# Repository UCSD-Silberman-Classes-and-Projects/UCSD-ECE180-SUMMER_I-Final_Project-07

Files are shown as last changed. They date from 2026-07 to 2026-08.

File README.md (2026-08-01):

# UCSD-ECE180-SUMMER_I-Final_Project-07

<div align="center">

</div>
  
</body>

<h1 align="center">Anti-Shrapnel Roomba</h1>
<h4 align="center"></h4>
<!-- PROJECT LOGO -->
<div align="center">

<h3>ECE 180 Final Project</h3>
<p>
Team 7 Summer I 26'
</p>

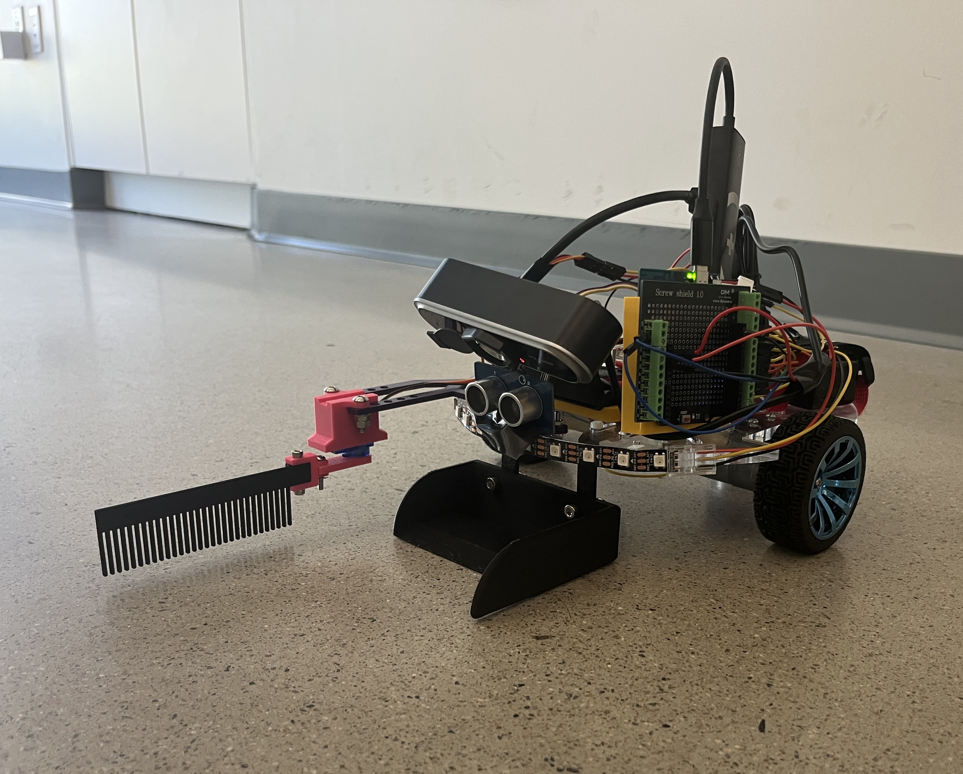
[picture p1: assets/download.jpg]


</div>

<!-- TABLE OF CONTENTS -->
<details>
  <summary>Table of Contents</summary>
  <ol>
    <li><a href="#team-members">Team Members</a></li>
    <li><a href="#final-project">Final Project</a></li>
      <ul>
        <li><a href="#original-goals">Original Goals</a></li>
          <ul>
            <li><a href="#goals-we-met">Goals We Met</a></li>
            <li><a href="#our-hopes-and-dreams">If We Have Another Week...</a></li>
         </ul>
       </ul>
    <li><a href="#final-project-documentation">Final Project Documentation</a></li>
    <ul>
      <li><a href="#CAD-Design">CAD Design </a></li>
      <ul>
            <li><a href="#modeled-ourselves">Modeled Ourselves</a></li>
            <li><a href="#open-source-parts">Open Source Parts</a></li>
          </ul>
        <li><a href="#Software">Software</a></li>
          <ul>
            <li><a href="#how-to-run">How to Run</a></li>
          </ul>
      </ul>
    <li><a href="#authors">Authors</a></li>
    <li><a href="#acknowledgments">Acknowledgments</a></li>
    <li><a href="#contact">Contact</a></li>
  </ol>
</details>

<!-- TEAM MEMBERS -->
## Team Members

<ul>
  <li>Raul -  Electrical Engineering - '27</li>
  <li>Tristan -  Electrical Engineering - '28</li>
  <li>AnMei - Computer Engineering - '27</li>
</ul>

<!-- Final Project -->
## Final Project
<!-- put stuff here -->

<!-- Original Goals -->
### Original Goals
Our initial goal was to build a Roomba-style robot that collects small hazardous objects (like sharp objects) from a workshop or playroom. Using an Arduino Uno Q with a webcam, the robot would identify sharp objects in its path. Must-have functionality included identifying sharp objects, collecting the identified objects, tracking how many objects were collected so as not to surpass the sweeper's hardcoded limit of 1, and navigating the space independently. Nice-to-have stretch functionality included ringing an alarm once the sweeper was full, having a child/baby mode (e.g. picking up Legos), and displaying the object count.
<!--example non visible text here -->
   
<!-- End Results -->
### Goals We Met
We successfully built a robot that identifies sharp objects, collects the identified objects, and tracks how many objects are collected so as not to surpass the sweeper's limit, all while navigating spaces independently although it still has bugs and inconsistencies. This can be seen in the demo below. We also succeeded in displaying the object count, going beyond our must-haves and hitting one of our nice-to-haves. For object detection, we initially planned to use a YOLO pro nano model but found it too laggy, so we used a FOMO model instead which made slightly quicker inferences.

### If We Have Another Week...
If we had one more week, we would implement a gyro (IMU) to improve direction in robot navigation as the current build using encoders and PID is effective but not perfect. We would also add a user interface to to allow users to give a rough estimate of the play area or area to be covered by the robot as it is currently hardcoded. Additionally, we would also try to improve the accuracy of our computer vision model as only two of several trained objects were picked up with one of them being inconsistent. We would also move the current location of the ultrasonic sensor and make another mount for the ultrasonic sensor as it's currently location underneath the camera would sometimes be set off at random times. This would happen rarely but is still an issue needing to be addressed. We would also improve the design of the current brush and dustbin as the current build would sometimes cause bigger objects to not be caught. The brush needs improved griping capabilities and the dustbin just needs to be made wider.

## Final Project Documentation

<!-- Early Quarter -->
### CAD Design
<!--<img src="/media/full%20car%20cad.png" width="400" height="300" />-->

#### Modeled Ourselves
| Part | CAD Model |
|---|---|
| Uno Q | <a href="assets/U Mount.stl"> Case Mount|
| Dustbin | <a href="assets/Dustbin.stl"> Extended Dustbin|
| Brush | <a href="assets/Comb.stl"> Brush|
| Servo | <a href="assets/Arm.stl"> Servo Arm Connector|
| Servo | <a href="assets/Hinges.stl"> Hinge to connect Comb and Servo|
| Ultrasonic Sensor | <a href="assets/Sensor Mount.stl"> Sensor Mount|

#### Open Source Parts
| Part | CAD Model |
|---|---|
| Uno Q Case | <a href="assets/arduino-uno-q-case.3mf"> Case|
| Servo | <a href="assets/SG90%20Servo%20Mount.stl"> Mount|

### Software / App Lab setup
- Arduino App Lab, with this project's Bricks added (via App Lab's Brick UI,
  not just imported in code):
  - **Video Object Detection** -- with your trained AI model selected under
    its "AI models" tab
  - **Web UI** -- serves the camera viewer / item counter page in the browser
- `sketch/sketch.ino` requires the **Servo** library (installed automatically
  by App Lab from the sketch's library list)
- `python/main.py` requires `pygame` (for the joystick placeholder --
  currently unused by autonomous mode itself, but imported)

#### Component List
| Component | Purpose|
|---|---|
| Arduino Uno Q | On board compute |
| SG 90 Micro Servo | To make brush do sweeping motion |
| Ultrasonic Ranger Sensor | To prevent bot from crashing into walls or furniture|
| PDB-XPW | Provide/distribute power from 3 Cell 12 V Lipo Battery to robot |
| L298N Motor Driver | Controls speed, direction, power of 2 DC motors |
| 2 JGA25-370 6V DC Motors with Encoders | Allows the robot to navigate with more precision with encoders |
| Generic 1080P 5V Webcam | Allow AI model to determine identity of objects |
| USB C Hub | Connects Arduino and Webcam to one another while also providing power from PDB |
| 3 Cell 12 V Lipo Battery | Provides power to entire robot |

### Wiring
| Component | Pin |
|---|---|
| Left motor ENA / IN1 / IN2 | D9 / D4 / D5 |
| Right motor ENB / IN3 / IN4 | D3 / D6 / D7 |
| Left encoder (Yellow) | D8 |
| Right encoder (Yellow) | D2 |
| Ultrasonic SIG | D10 |
| Sweeper servo | D11 |

## How to run

1. Using Encoder Calibration files, run the app to calibrate encoders for first time use. Can skip if already set.
2. Using Ultrasonic Sensor Testing files, run a few sets measurements of sensor are accurate as this can throw off limits set for wall or furniture detection. Can skip if already checked.
3. Open Autonomous Movement with Cam project in App Lab and hit **Run**.
4. The app waits `STARTUP_DELAY_SECONDS` (currently 5s) before any movement
   starts, giving the camera stream time to come up. Use this window to open
   the WebUI in your browser (it doesn't always auto-pop-up -- see
   Troubleshooting below).
5. Movement mode is controlled by `TEST_MODE` near the top of `main.py`:

| `TEST_MODE` | What it does |
|---|---|
| `"drive"` | Drives forward `TEST_DRIVE_DISTANCE_CM` once, no camera checks |
| `"turn"` | Turns `TEST_TURN_DEGREES` in place, no camera checks |
| `"creep"` | One row, in small increments, pausing for the camera between each -- pickup/avoid/obstacle all active, with camera checks |
| `"creep2"` | Two rows (creep mode) with a turn in between, with camera checks |
| `"sweep2"` | Two rows, full continuous speed, **no** camera checks (movement/turn-geometry test only) |
| `"sweep"` | Full lawnmower coverage of the whole play area, no camera checks |

Set the mode, save, and hit Run again.

## Troubleshooting

- **WebUI doesn't auto-pop-up**: check App Lab's own preview/open link, or
  navigate to `http://localhost:7000` (or the board's network IP) manually.
  This has been unreliable but is cosmetic -- the app works fine either way.
- **Behavior doesn't match your latest code change**: do a clean rebuild
  before assuming the code is wrong:
  ```
  cd ~/ArduinoApps/autonomous-movement-with-cam
  docker compose -f .cache/app-compose.yaml down
  rm -rf .cache
  ```
  Then hit Run again in App Lab. Worth doing anytime you change Bricks,
  `app.yaml`, or the WebUI's static files (`index.html`/`app.js`).
- **Sketch fails to compile with "redefinition of ..." errors**: the file
  wasn't fully replaced when pasted -- clear `sketch/sketch.ino` completely
  before pasting in a new version, don't paste on top of existing content.
- ** Ultrasonic Testing files included if issues come up with sensor.

## Final Project Presentation Slides
<a href= "https://docs.google.com/presentation/d/1Zw6ZW6a8-33r7sMMGZXmiMXOQ0kt0MH9-cVSyJLGKLM/edit?usp=sharing">Final Project Demonstration Slides

## Video Demos
<a href= "https://youtube.com/shorts/Sm3MTq7GF2I?feature=share">Robot Navigating Demo

<a href= "https://youtube.com/shorts/Sm3MTq7GF2I?feature=share">Robot Avoiding Non-sharp Object Demo

<a href= "https://youtube.com/shorts/Sm3MTq7GF2I?feature=share">Robot Sweeps Sharp Object Demo

<a href= "https://youtube.com/shorts/Sm3MTq7GF2I?feature=share">Robot Fails to Sweep Sharp Object Demo

## FOMO Model
<a href= "https://studio.edgeimpulse.com/public/1059185/latest">Here 

<!-- Authors -->
## Authors

Raul, Tristan, and AnMei

<!-- ACKNOWLEDGMENTS -->
## Acknowledgments
Much appreciation to Professor Silberman, TA Jose, and classmates.

<!-- CONTACT -->
## Contact

* Raul | rbmagana@ucsd.edu
* Tristan | ttjussardi@ucsd.edu
* AnMei | adasbachprisk@ucsd.edu

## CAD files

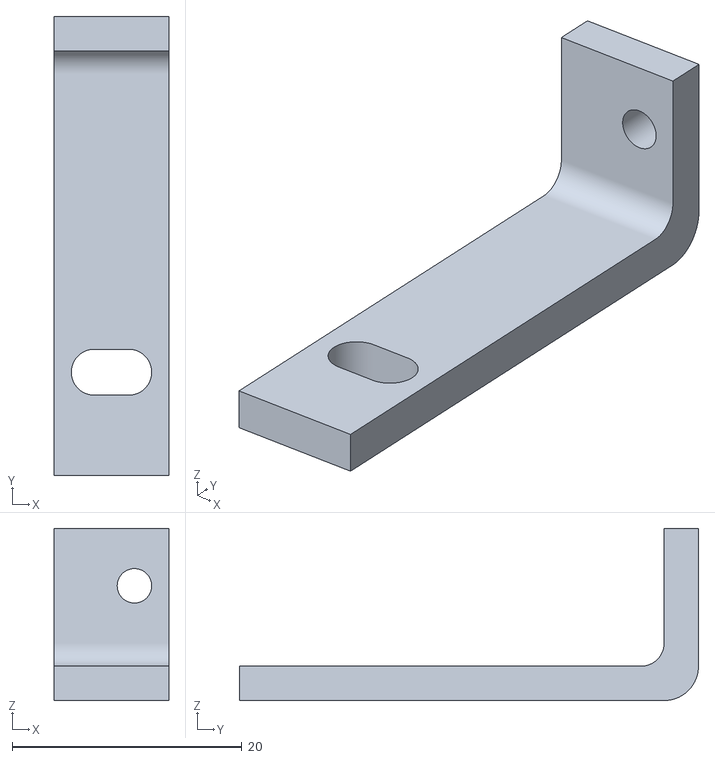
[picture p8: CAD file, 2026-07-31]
assets/Hinges.stl
10.0 x 40.0 x 15.0

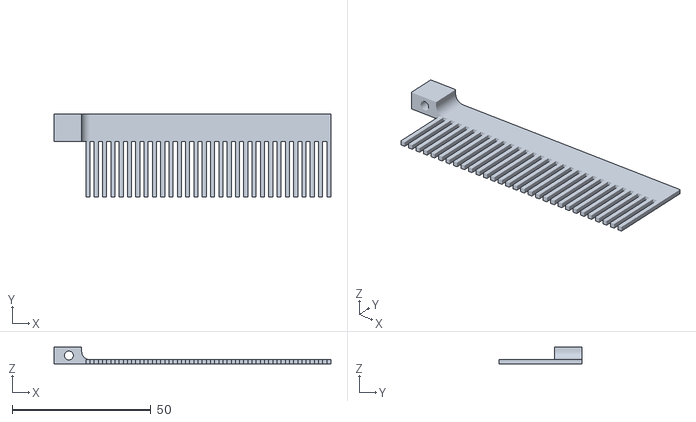
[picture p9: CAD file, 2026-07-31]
assets/Comb.stl
100.0 x 30.0 x 6.00

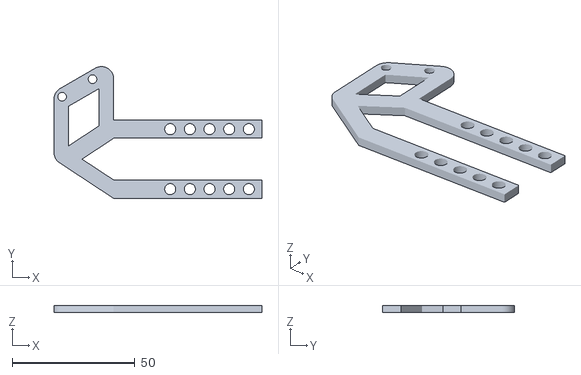
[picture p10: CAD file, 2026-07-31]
assets/Servo Mount.stl
84.6 x 53.7 x 3.00

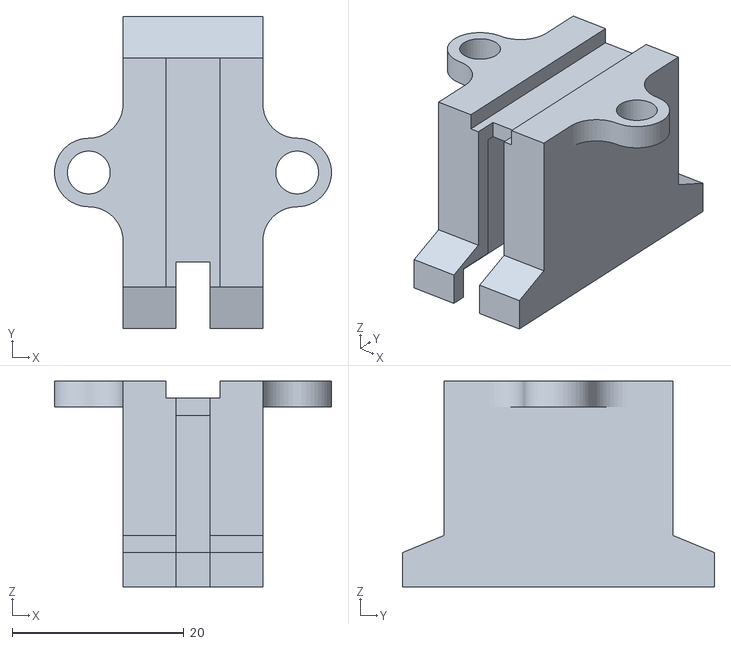
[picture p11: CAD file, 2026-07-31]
assets/SG90%20Servo%20Mount.stl
32.3 x 36.4 x 24.0

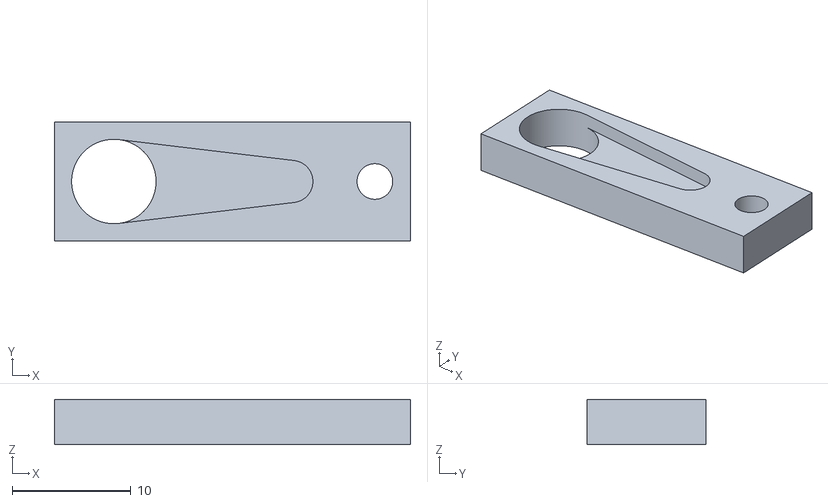
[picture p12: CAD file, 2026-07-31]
assets/Arm.stl
30.0 x 10.0 x 3.80

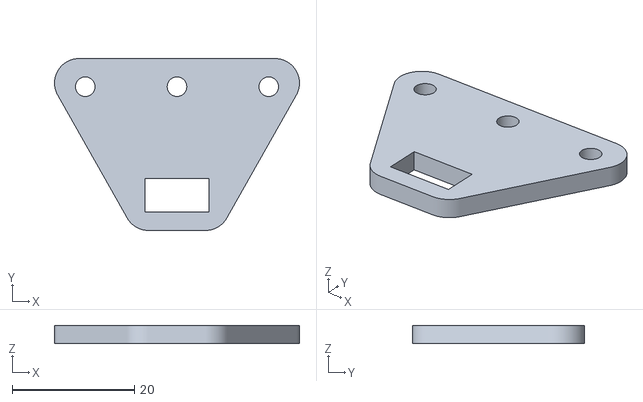
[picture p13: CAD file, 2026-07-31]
assets/Sensor Mount.stl
40.1 x 28.1 x 3.00

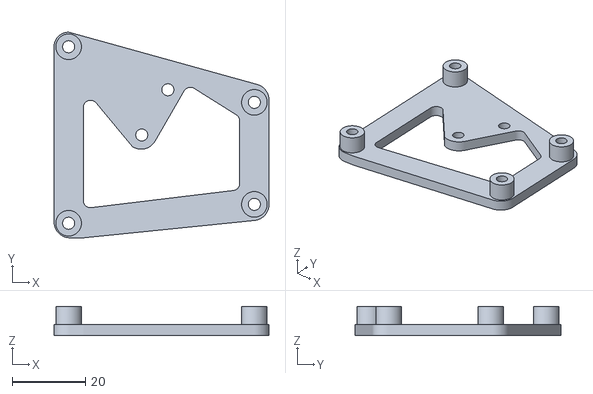
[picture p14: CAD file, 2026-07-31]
assets/Arduino Mount.stl
58.8 x 56.3 x 8.00

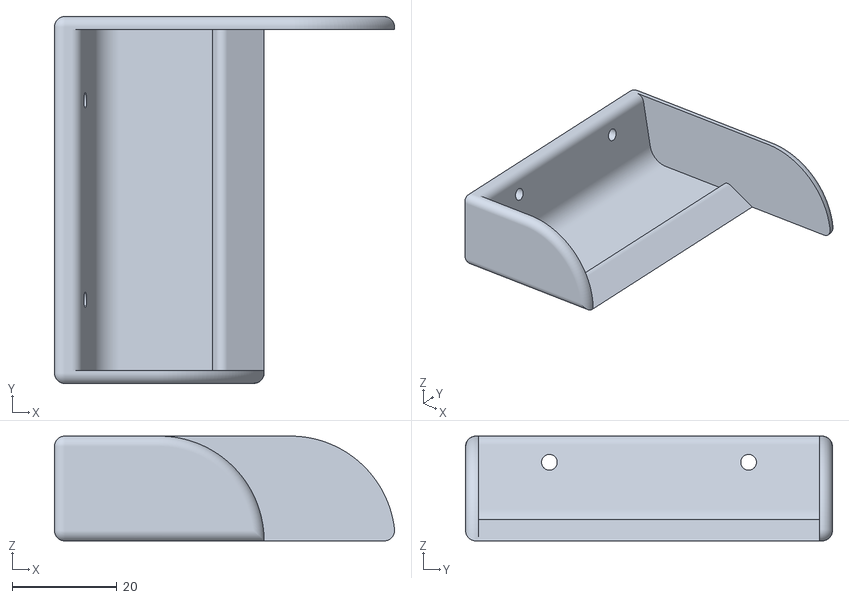
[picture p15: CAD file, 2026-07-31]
assets/Dustbin.stl
64.9 x 70.0 x 20.0

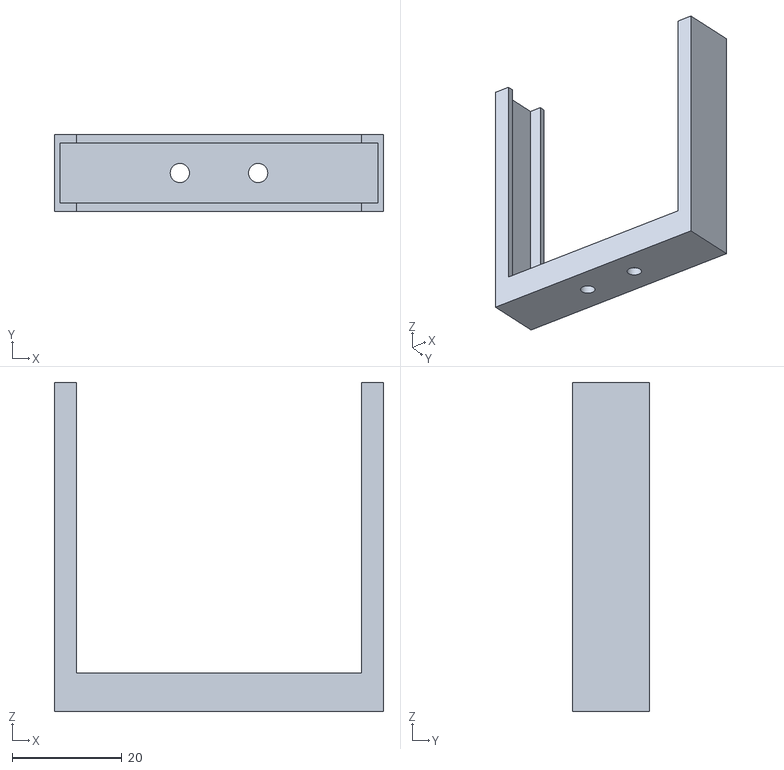
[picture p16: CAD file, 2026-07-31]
assets/U Mount.stl
60.0 x 14.0 x 60.0

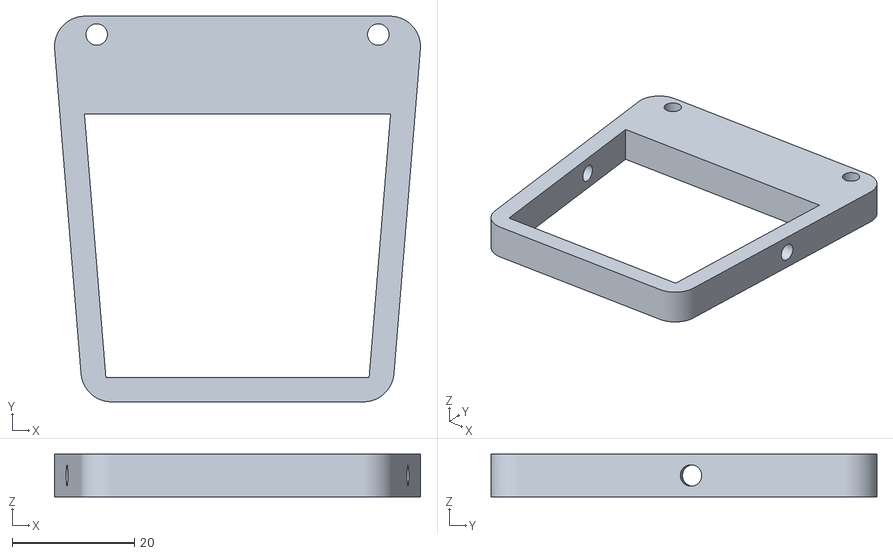
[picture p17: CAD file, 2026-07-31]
assets/Camera Mount.stl
59.8 x 63.0 x 7.00

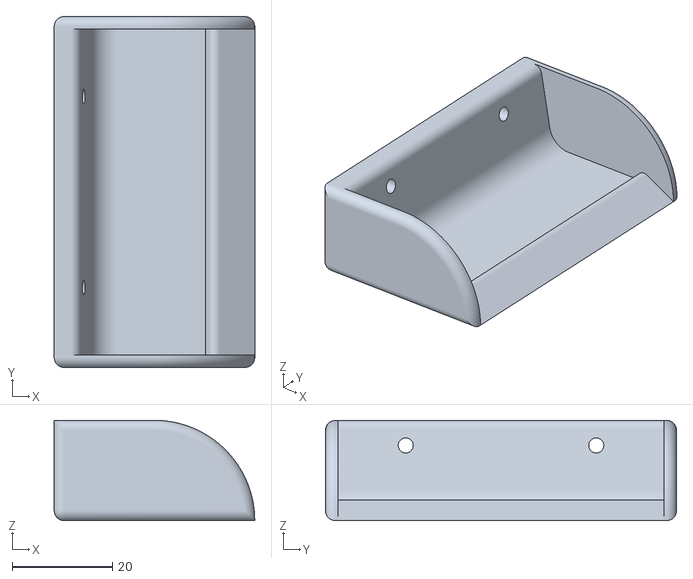
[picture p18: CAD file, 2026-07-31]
assets/Dustbin #1.stl
40.0 x 70.0 x 20.0

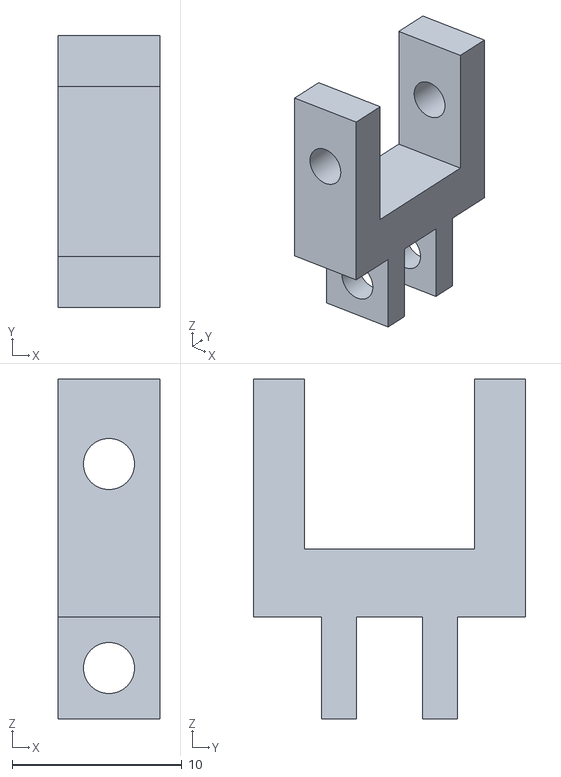
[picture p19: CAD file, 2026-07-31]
assets/Connector.stl
6.00 x 16.0 x 20.0

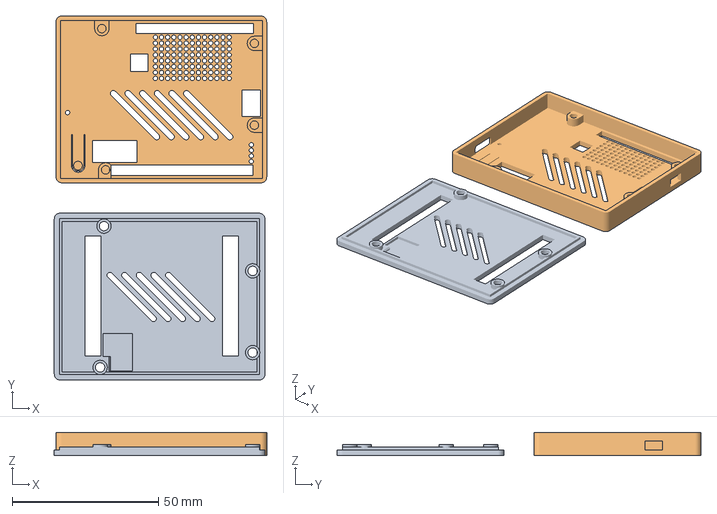
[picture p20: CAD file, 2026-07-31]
assets/arduino-uno-q-case.3mf
72.6 x 124.4 x 8.00 mm
arduino-uno-q-case-bottom.stl
arduino-uno-q-case-top.stl

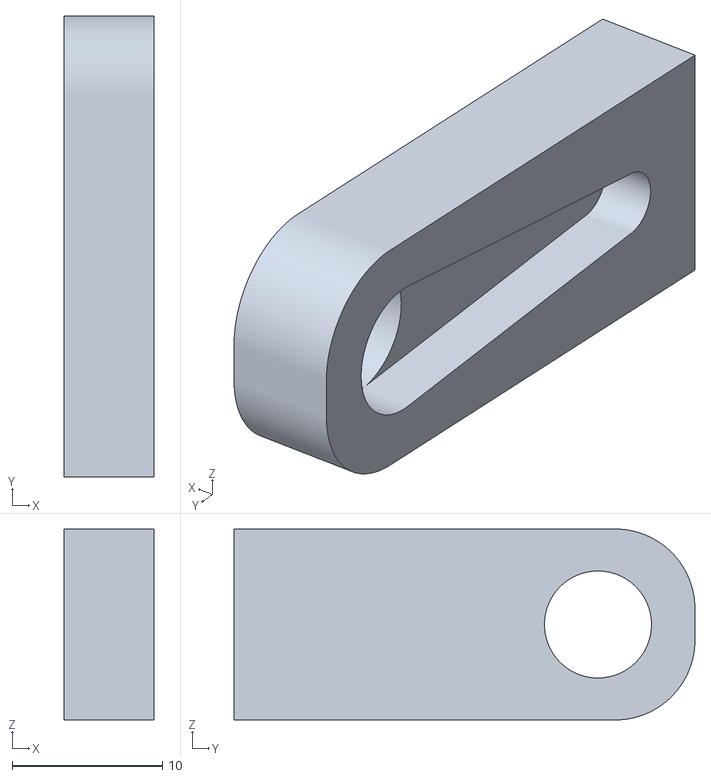
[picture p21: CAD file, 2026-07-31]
assets/Arm test piece.stl
6.00 x 30.7 x 12.7

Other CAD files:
assets/Hinges Inverted.stl

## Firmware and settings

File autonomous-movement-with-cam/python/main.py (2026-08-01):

"""
Autonomous movement primitives — Uno Q MPU (Linux) side.
Uses encoder feedback for closed-loop, distance/angle-accurate movement
instead of open-loop timing. Reuses the same Bridge RPC functions as
manual teleop (set_motors, stop_motors, get_encoder_counts,
reset_encoder_counts, get_distance).

This file goes in your App Lab project's: python/main.py

TESTING THIS FILE:
  Start with TEST_MODE = "drive" to test drive_forward_cm() alone,
  then TEST_MODE = "turn" to test turn_degrees() alone, before trying
  the full sweep. Each prints its progress so you can verify accuracy
  against a tape measure / protractor before trusting it.
"""

from arduino.app_utils import *
from arduino.app_bricks.web_ui import WebUI
from arduino.app_bricks.video_objectdetection import VideoObjectDetection
from datetime import datetime, UTC
import time
import math
import pygame

# ---- Camera / AI detection ----
# Matches your trained model's actual class labels.
CATEGORY_PICKUP = "screw"
AVOID_CATEGORIES = {"adapter", "baby hazard"}

# Only treat a detection as "close enough to act on" if its bounding
# box's bottom edge (y2) is at or below this many pixels from the top
# of the frame (assumes ~640x480 camera resolution). Two separate
# thresholds since pickup and avoid need different reaction distances:
# pickup only needs to trigger once actually close (brush range), but
# avoid needs to trigger further away to leave room/time for the
# sidestep-bypass-return maneuver.
PICKUP_Y_THRESHOLD = 240  # calibrated in Manual Movement: object placed where the brush could reach it measured y2=240
AVOID_Y_THRESHOLD = 120   # further away (smaller y2) than pickup, to react before the robot is right on top of it

# ---- Camera viewer web interface ----
# This is what actually serves the browser page showing the camera
# feed/detections -- without it, the AI model still runs and
# detections still fire, but there's nothing to view in a browser.
# NOTE: created BEFORE VideoObjectDetection, matching Manual Movement's
# ordering -- VideoObjectDetection can take real time to initialize
# (loading the AI model, starting the camera stream), and creating it
# first was suspected to delay the WebUI past whatever window App
# Lab's auto-popup logic watches for.
ui = WebUI()
detection_stream = VideoObjectDetection(confidence=0.5, debounce_sec=0.0)
ui.on_message("override_th", lambda sid, threshold: detection_stream.override_threshold(threshold))

# Set by on_detections() whenever something close enough is seen and
# nothing is currently pending. Cleared once the creep-and-check loop
# (or sweep) has acted on it. This mirrors the awaiting_decision/
# detected_category pattern from the Manual Movement app so both apps
# behave consistently.
awaiting_decision = False
detected_category = None

# Total number of items successfully picked up this run. Sent to the
# WebUI's "Item Count" badge each time it changes.
item_count = 0

# Creeping only stops for a pickup once this many items have been
# collected -- below this, a pickup sweeps the brush and continues
# through the rest of the row. Set to 1 for now (current test setup:
# stop after the first item), but this can be raised once you're
# ready to test collecting multiple items per row.
MAX_ITEMS_TO_PICKUP = 1


def increment_item_count():
    global item_count
    item_count += 1
    ui.send_message("item_count", message=item_count)
    print(f"Item count: {item_count}")


def on_detections(detections: dict):
    """Callback fired by the Brick whenever objects are detected.
    detections is shaped like:
      {category_name: [ {"confidence": ..., "bounding_box_xyxy": (x1,y1,x2,y2)}, ... ]}

    Only acts on a detection if its bounding box's bottom edge (y2) is
    past that category's threshold -- i.e. close enough to actually
    act on, not just visible somewhere in frame. Pickup and avoid use
    different thresholds (see PICKUP_Y_THRESHOLD / AVOID_Y_THRESHOLD
    above), since avoid needs more reaction distance than pickup.
    """
    global awaiting_decision, detected_category

    for category, values in detections.items():
        for value in values:
            entry = {
                "content": category,
                "confidence": value.get("confidence"),
                "timestamp": datetime.now(UTC).isoformat()
            }
            ui.send_message("detection", message=entry)

        if awaiting_decision:
            continue  # already handling one -- keep sending to WebUI, but don't act on more

        if category == CATEGORY_PICKUP:
            threshold = PICKUP_Y_THRESHOLD
        elif category in AVOID_CATEGORIES:
            threshold = AVOID_Y_THRESHOLD
        else:
            continue  # unrecognized category -- shown in WebUI above, but no action

        for detection in values:
            bbox = detection.get("bounding_box_xyxy")
            if bbox is None:
                continue
            _, _, _, y2 = bbox

            if y2 >= threshold:
                awaiting_decision = True
                detected_category = category
                confidence = detection.get("confidence")
                print(f"DETECTED (close enough): {category} "
                      f"(confidence {confidence}, y2={y2}, threshold={threshold})")
                break
            # else: detected, but still too far away -- ignore for now,
            # keep creeping closer and check again next frame.


detection_stream.on_detect_all(on_detections)

# ---- Set this to test one piece at a time ----
# "drive"   -> tests driving forward a fixed distance
# "turn"    -> tests turning a fixed angle
# "creep"   -> tests creep_forward_cm() alone (stop-scan-move + camera check)
# "creep2"  -> tests one row, turn, second row (creep_two_rows())
# "sweep2"  -> two rows, full speed, no creep increments (drive_two_rows_full())
# "sweep"   -> runs the full lawnmower sweep
TEST_MODE = "creep2"
TEST_DRIVE_DISTANCE_CM = 100
TEST_TURN_DEGREES = 90

# Confirm this via jstest — button number that changes when you press X.
START_BUTTON = 1  # X — confirmed via jstest

# ---- Robot geometry (measured) ----
WHEEL_DIAMETER_CM = 6.5
WHEEL_CIRCUMFERENCE_CM = math.pi * WHEEL_DIAMETER_CM

# NOTE: this is an *effective* wheelbase, not the physically-measured
# one (that measured ~19.5cm). It's been empirically corrected to
# account for wheel scrub during point turns on vinyl flooring --
# using the true measured wheelbase caused turns to overshoot
# (commanded 90 degrees actually turned ~115 degrees). This corrected
# value was confirmed to produce ~90 degree actual turns (85-95 degree
# repeatable range) on a 90 degree command.
WHEELBASE_CM = 15.3

ROBOT_WIDTH_CM = 24

# Effective row spacing for the lawnmower sweep. Deliberately tighter
# than ROBOT_WIDTH_CM to build in overlap margin -- this accounts for
# (a) measured straight-line drift of up to ~10cm over a 300cm run,
# and (b) general good-practice overlap so objects sitting near a row
# boundary aren't missed even in the best case.
ROW_SPACING_CM = 18

PLAY_AREA_WIDTH_CM = 300
PLAY_AREA_LENGTH_CM = 300

# ---- Calibrated encoder constants ----
# Re-derived via hand-spin calibration (10 full revolutions per wheel,
# raw pulse counts read via get_encoder_counts()) after the board
# rebuild -- confirmed different from the old board's values,
# especially on the right wheel (257 -> 249).
PULSES_PER_REV_LEFT = 248
PULSES_PER_REV_RIGHT = 249

# Empirical correction factor — commanded 50cm actually traveled ~60cm,
# meaning our distance-per-pulse estimate was too low by this ratio.
# Multiplying corrects for it. Adjust further based on repeated testing.
DISTANCE_CORRECTION_FACTOR = 60 / 50

# ---- Speed settings (reuse your tuned manual-driving values) ----
MIN_PWM = 65           # matches your tuned manual-driving MIN_PWM
MAX_PWM = 95           # matches your tuned manual-driving MAX_PWM
DRIVE_PWM = 95        # base speed for forward/backward moves
TURN_PWM = 95         # speed used while turning in place

# Re-derived at DRIVE_PWM=95/MIN_PWM=65 via careful PID-off comparison
# across trim=9/10/11 -- all three averaged within noise of each other
# (~3 unit average |error| over 100cm), so 10 was picked as a
# reasonable middle value rather than continuing to chase run-to-run
# noise. This ~3-unit residual wobble is what Kp now needs to handle,
# not the much larger sustained bias seen at the old trim=15.
LEFT_TRIM = 10
RIGHT_TRIM = 0

# Set False to test raw, uncorrected driving (fixed trim only) for
# comparison against the PID-corrected version.
USE_PID_CORRECTION = True

# ---- Obstacle avoidance ----
# 30cm gives buffer beyond the ~18cm brush-tip distance to absorb
# sensor/polling lag and motor coast distance before actually stopping.
OBSTACLE_THRESHOLD_CM = 30
AVOID_BACKUP_CM = 10
AVOID_TURN_DEGREES = 45

# ---- Polling ----
POLL_INTERVAL = 0.05


def get_counts():
    result = Bridge.call("get_encoder_counts")
    left_str, right_str = result.split(",")
    return int(left_str), int(right_str)


def pulses_to_distance(pulses, pulses_per_rev):
    return (pulses / pulses_per_rev) * WHEEL_CIRCUMFERENCE_CM * DISTANCE_CORRECTION_FACTOR


def check_obstacle():
    """Returns True if something is closer than OBSTACLE_THRESHOLD_CM."""
    distance = Bridge.call("get_distance")
    return 0 < distance < OBSTACLE_THRESHOLD_CM


def drive_forward_cm(distance_cm, speed=DRIVE_PWM):
    """Drives forward (or backward if distance_cm is negative) using
    encoder feedback to stop at the target distance. Returns "done" if
    it completed the distance, or "obstacle" if it stopped early due
    to something being detected in range."""
    direction = 1 if distance_cm >= 0 else -1
    target_cm = abs(distance_cm)

    Bridge.call("reset_encoder_counts")
    left_start, right_start = 0, 0

    final_left_pwm = int(direction * (speed + LEFT_TRIM))
    final_right_pwm = int(direction * (speed + RIGHT_TRIM))

    # Brief ramp-up instead of an instant full-power start — reduces
    # inconsistent curving caused by an abrupt step command.
    RAMP_STEPS = 5
    RAMP_DURATION = 0.25  # seconds
    for step in range(1, RAMP_STEPS + 1):
        fraction = step / RAMP_STEPS
        ramp_left = int(final_left_pwm * fraction)
        ramp_right = int(final_right_pwm * fraction)
        Bridge.call("set_motors", ramp_right, ramp_left)
        time.sleep(RAMP_DURATION / RAMP_STEPS)

    result = "done"
    # PID gains for real-time left/right balancing.
    # Kp=3.5 (tuned to fight the old trim=15 sustained bias) was found
    # to make things WORSE than PID-off once the real cause turned out
    # to be trim, not a lack of correction authority -- correction was
    # pinning at MAX_CORRECTION and pushing error higher, not lower.
    # Resetting to a low starting point and re-tuning carefully now
    # that trim=10 leaves only a small ~3-unit residual wobble to
    # correct, rather than a large sustained bias.
    Kp = 1.0
    Ki = 0.0
    Kd = 0.0
    MAX_CORRECTION = 25  # loosened — the separate MIN_PWM floor already prevents stalling
    print(f"DEBUG: USE_PID_CORRECTION={USE_PID_CORRECTION} Kp={Kp} Ki={Ki} Kd={Kd} MAX_CORRECTION={MAX_CORRECTION} PULSES_PER_REV_LEFT={PULSES_PER_REV_LEFT} PULSES_PER_REV_RIGHT={PULSES_PER_REV_RIGHT}")

    integral_error = 0.0
    MAX_INTEGRAL = MAX_CORRECTION / max(Ki, 0.0001)  # clamp so Ki*integral alone can't exceed MAX_CORRECTION

    # Prime the derivative term with a real reading first, so the loop's
    # first iteration doesn't see a fake jump from 0 (the "derivative
    # kick" that caused a large spurious correction spike at startup).
    left_count, right_count = get_counts()
    left_dist = pulses_to_distance(left_count - left_start, PULSES_PER_REV_LEFT)
    right_dist = pulses_to_distance(right_count - right_start, PULSES_PER_REV_RIGHT)
    previous_error = left_dist - right_dist
    previous_time = time.time()

    try:
        while True:
            left_count, right_count = get_counts()
            left_dist = pulses_to_distance(left_count - left_start, PULSES_PER_REV_LEFT)
            right_dist = pulses_to_distance(right_count - right_start, PULSES_PER_REV_RIGHT)

            now = time.time()
            dt = max(now - previous_time, 0.001)  # avoid divide-by-zero

            error = left_dist - right_dist  # positive = left ahead of right

            if USE_PID_CORRECTION:
                integral_error += error * dt
                integral_error = max(-MAX_INTEGRAL, min(MAX_INTEGRAL, integral_error))
                derivative = (error - previous_error) / dt

                correction = (Kp * error) + (Ki * integral_error) + (Kd * derivative)
                correction = max(-MAX_CORRECTION, min(MAX_CORRECTION, correction))
            else:
                correction = 0  # no dynamic correction — fixed trim only

            previous_error = error
            previous_time = now

            corrected_left_mag = max(MIN_PWM, abs(final_left_pwm) - correction)
            corrected_right_mag = max(MIN_PWM, abs(final_right_pwm) + correction)

            corrected_left_pwm = int(direction * corrected_left_mag)
            corrected_right_pwm = int(direction * corrected_right_mag)

            Bridge.call("set_motors", corrected_right_pwm, corrected_left_pwm)

            print(f"  error={error:.1f} correction={correction:.1f} L_pwm={corrected_left_pwm} R_pwm={corrected_right_pwm} avg_dist={((left_dist+right_dist)/2.0):.1f}")

            if check_obstacle():
                result = "obstacle"
                break

            avg_dist = (left_dist + right_dist) / 2.0
            if avg_dist >= target_cm:
                break

            time.sleep(POLL_INTERVAL)
    finally:
        Bridge.call("stop_motors")

    return result


def turn_degrees(degrees, speed=TURN_PWM):
    """Turns in place by the given angle. Positive = turns right,
    negative = turns left (confirmed via testing). Uses encoder
    feedback on both wheels spinning in opposite directions to
    measure actual rotation achieved."""
    direction = 1 if degrees >= 0 else -1
    target_rad = math.radians(abs(degrees))
    target_arc_cm = (WHEELBASE_CM / 2.0) * target_rad

    Bridge.call("reset_encoder_counts")

    # Point turn: wheels spin in opposite directions at equal speed.
    left_pwm = int(direction * speed)
    right_pwm = int(-direction * speed)

    Bridge.call("set_motors", right_pwm, left_pwm)  # swapped, see teleop notes

    try:
        while True:
            Bridge.call("set_motors", right_pwm, left_pwm)  # keep failsafe from tripping

            left_count, right_count = get_counts()
            left_dist = pulses_to_distance(left_count, PULSES_PER_REV_LEFT)
            right_dist = pulses_to_distance(right_count, PULSES_PER_REV_RIGHT)
            avg_arc = (left_dist + right_dist) / 2.0

            if avg_arc >= target_arc_cm:
                break

            time.sleep(POLL_INTERVAL)
    finally:
        Bridge.call("stop_motors")


def check_for_target():
    """Returns the detected category (e.g. "sharp wire", "baby hazard")
    if something is currently pending a decision, or None if nothing
    has been detected since the last time this was cleared.

    Does NOT clear awaiting_decision itself -- the caller (creep loop /
    sweep) is responsible for deciding what to do and then calling
    clear_detection() once it's been handled.
    """
    if awaiting_decision:
        return detected_category
    return None


def clear_detection():
    """Marks the current pending detection as handled, allowing new
    detections to be picked up again."""
    global awaiting_decision, detected_category
    awaiting_decision = False
    detected_category = None


# ---- Creep-and-check ----
# The camera/AI pipeline has real processing latency -- testing in the
# Manual Movement app showed it can miss objects even at normal driving
# speed, not just fast passes. Rather than continuous driving, we creep
# forward in short increments and fully stop+pause after each one, so
# the camera gets a real chance to process a still (or near-still)
# frame every time, instead of trying to catch a moving target.
CREEP_INCREMENT_CM = 5
CREEP_PAUSE_SECONDS = 4.0

# ---- Avoid maneuver ----
# When an AVOID_CATEGORIES object is detected close enough, the robot
# sidesteps into the adjacent row, drives past the object, then
# returns to the original row -- a rectangular detour rather than a
# diagonal cut, so it stays aligned with the row/turn geometry already
# validated for the sweep.
AVOID_SIDESTEP_CM = ROW_SPACING_CM  # lateral distance to the adjacent row
AVOID_BYPASS_CM = 40  # how far to drive forward while bypassing the object -- adjust based on real object/obstacle size



def avoid_obstacle():
    """Executes a rectangular sidestep maneuver to get around a
    detected avoid-category object (e.g. "adapter", "baby hazard"),
    then returns to the original row facing the original direction.
    Turns are relative to the robot's current heading, so this works
    regardless of which row/turn-direction the sweep is currently on.

    Sequence: turn right -> check clearance -> sidestep into adjacent
    row -> turn left (now facing original direction again) -> drive
    forward past the object -> turn left again -> return sidestep back
    to the original row -> turn right (facing original direction,
    back on the original row, having advanced AVOID_BYPASS_CM).

    Returns True if the maneuver completed and it's safe to keep
    creeping, or False if the ultrasonic sensor found the sidestep
    path blocked too -- in which case it stops immediately without
    attempting to undo the first turn (no further recovery logic
    implemented yet).
    """
    print("Avoid maneuver: turning right 90 degrees to check clearance...")
    turn_degrees(90)

    distance = Bridge.call("get_distance")
    if 0 < distance < OBSTACLE_THRESHOLD_CM:
        print(f"Path blocked on the right too (distance={distance:.1f}cm) -- "
              f"aborting avoid maneuver.")
        return False

    print(f"Clear. Sidestepping {AVOID_SIDESTEP_CM}cm to the adjacent row...")
    drive_forward_cm(AVOID_SIDESTEP_CM)

    print("Turning left 90 degrees to resume original heading...")
    turn_degrees(-90)

    print(f"Driving forward {AVOID_BYPASS_CM}cm to pass the object...")
    drive_forward_cm(AVOID_BYPASS_CM)

    print("Turning left 90 degrees to head back toward the original row...")
    turn_degrees(-90)

    print(f"Returning {AVOID_SIDESTEP_CM}cm to the original row...")
    drive_forward_cm(AVOID_SIDESTEP_CM)

    print("Turning right 90 degrees to resume original heading...")
    turn_degrees(90)

    print("Avoid maneuver complete -- resuming row.")
    return True
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

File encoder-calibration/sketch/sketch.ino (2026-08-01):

/*
  Encoder Calibration app — Uno Q MCU side.
  Standalone app for manually calibrating PULSES_PER_REV_LEFT/RIGHT by
  hand-spinning each wheel a known number of revolutions and reading
  raw pulse counts before/after.

  This file goes in your App Lab project's: sketch/sketch.ino

  Wiring:
    Left encoder:  D8  (Yellow signal wire; Blue=3.3V, Black=GND)
    Right encoder: D2  (Yellow signal wire; Blue=3.3V, Black=GND)

  No motor pins needed — this app only counts pulses while you hand-spin
  each wheel. Motors are left disconnected/unused here.

  Exposes RPC functions that the Python (MPU) side calls:
    get_encoder_counts()    -> returns "left,right" pulse counts as a string
    reset_encoder_counts()  -> zeros both counters
*/

#include "Arduino_RouterBridge.h"

const int LEFT_ENCODER_PIN = 8;
const int RIGHT_ENCODER_PIN = 2;

volatile unsigned long leftPulseCount = 0;
volatile unsigned long rightPulseCount = 0;

// Same debounce filtering used in the main autonomous sketch.
const unsigned long DEBOUNCE_MICROS = 300;
volatile unsigned long lastLeftPulseMicros = 0;
volatile unsigned long lastRightPulseMicros = 0;

void leftEncoderISR() {
  unsigned long now = micros();
  if (now - lastLeftPulseMicros > DEBOUNCE_MICROS) {
    leftPulseCount++;
    lastLeftPulseMicros = now;
  }
}

void rightEncoderISR() {
  unsigned long now = micros();
  if (now - lastRightPulseMicros > DEBOUNCE_MICROS) {
    rightPulseCount++;
    lastRightPulseMicros = now;
  }
}

void setup() {
  pinMode(LEFT_ENCODER_PIN, INPUT);
  pinMode(RIGHT_ENCODER_PIN, INPUT);
  attachInterrupt(digitalPinToInterrupt(LEFT_ENCODER_PIN), leftEncoderISR, RISING);
  attachInterrupt(digitalPinToInterrupt(RIGHT_ENCODER_PIN), rightEncoderISR, RISING);

  Bridge.begin();
  Bridge.provide("get_encoder_counts", get_encoder_counts);
  Bridge.provide("reset_encoder_counts", reset_encoder_counts);
}

void loop() {
  // Nothing to do here — everything happens via RPC calls from Python.
}

String get_encoder_counts() {
  String result = String(leftPulseCount) + "," + String(rightPulseCount);
  return result;
}

bool reset_encoder_counts() {
  leftPulseCount = 0;
  rightPulseCount = 0;
  return true;
}
